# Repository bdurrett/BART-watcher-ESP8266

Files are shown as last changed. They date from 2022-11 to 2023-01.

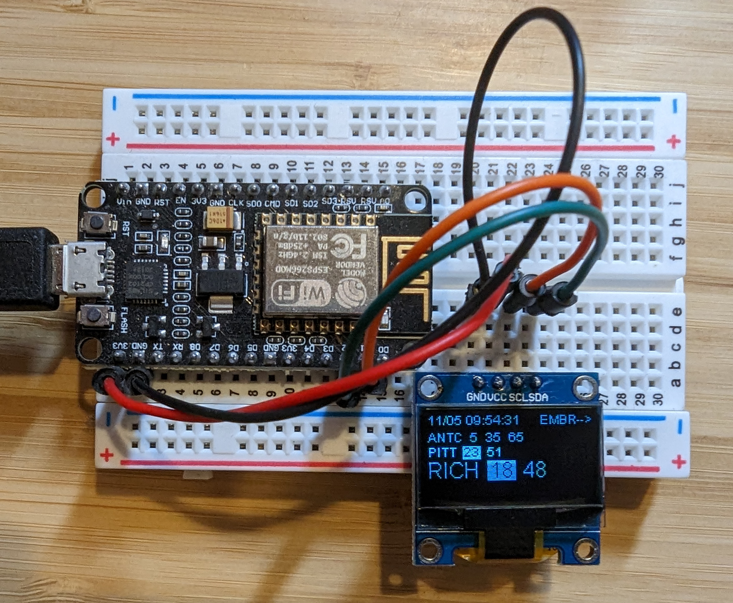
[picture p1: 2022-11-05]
assets/images/BART watcher full build.jpeg

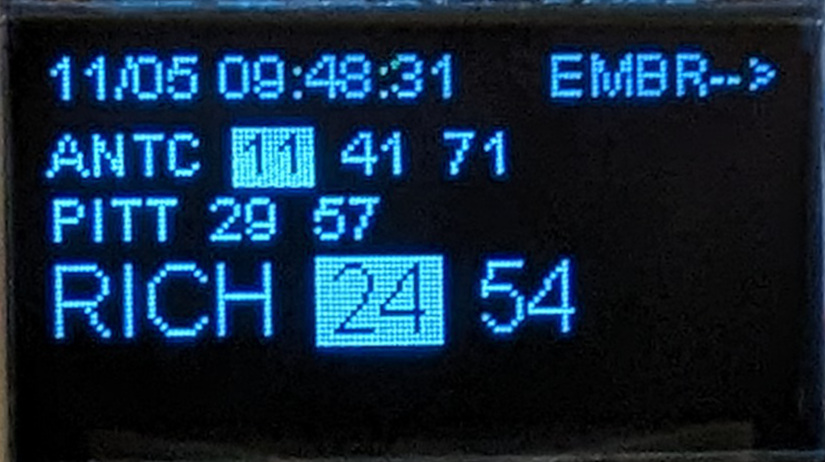
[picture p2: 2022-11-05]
assets/images/BART watcher screen closeup.jpeg

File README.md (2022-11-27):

# BART-watcher-ESP8266
Low power device to display relevant BART departures, ESP8266 and SSD1306 OLED display

## Overview
I frequently commute on BART and wanted a convenient way to tell when I should start walking to 
the train station, ideally something that is always accessible. Using a ESP8266 board and a ~1 inch
screen, I was able to see departing trains that meet my schedule.

The top line shows the date / time the station information was collected, and the departing 
station. The following lines are trains that are usable for the destination station, with the 
preferred (direct) lines in large type, and less-preferred (transfer needed) in small type. 
Finally, if a train is within the sweet spot where it isn't departing too soon to make it to 
the station but you also won't be waiting at the station too long, the departure time is 
highlighted, and the screen flashes briefly when updating to get attention.

* A number is minutes until departure
* "L" means the train is currently leaving
* "X" means the trains was cancelled (somewhat frequent these days)

In the example below, these are trains leaving Embarcadero for the North Berkeley station, Antioch and 
Berryessa Point lines require a transfer, Richmond line is direct. Two of the trains fit into the
departure sweet spot. 

Display close-up

### Interactive User Interface
If you add a button, a quick press will toggle the screen off and pause network updates. 
Another quick press will turn the screen back on and enable network updates. A long press (about 
3 seconds) will enter menu mode, where a quick press iterates through the menu items and a
long press exits menu mode. From the menu you can select the route (limited testing now) and
reset the wifi settings.

Menu

There is a little more contect on my blog, [BART Train Monitor with ESP8266 and SSD1306 display](https://brett.durrett.net/bart-train-monitor-with-esp8266-and-ssd1306-display/), and [3D Printed Case for ESP8266 and SSD1306 display](https://brett.durrett.net/3d-printed-case-for-esp8266-and-ssd1306-display/)

## Required Hardware
* ESP8266 board, any should work, [the ESP-12F is nice and tiny](https://smile.amazon.com/gp/product/B081PX9YFV/ref=ppx_yo_dt_b_asin_title_o01_s01?ie=UTF8&psc=1)
* SSD1306 OLED display, other types may work, I used [this one](https://smile.amazon.com/gp/product/B09C5K91H7/ref=ppx_yo_dt_b_asin_title_o01_s02?ie=UTF8&psc=1)

1. Connect ESP8266 D1, GPIO5 (SCL) to SCK on the SSD1306
2. Connect ESP8266 D2, GPIO4 (SDA) to SDA on the SSD1306
3. Connect ESP8266 GND and 3.3V to SSD1306 GND and VDD respectively

The completed build needs 4 wires and looks a little something like this (v1 screen layout shown):
BART watcher full build

### Optional Button
If you want to use the interactive hardware UI, install a momentary button!
* Some button (momentary switch)
* A 10 K ohm resistor (for pull down)

1. Connect ESP8266 D5, GPIO15 to one end of the switch
2. Connect one end ofthe 10 K ohm resistor to the same end of the switch, the other end of the resistor to GND
3. Connect the other end of the switch to 3.3V

With a button you get access to a menu! 

### Wiring Diagram

BART watcher wiring diagram

Wiring diagram created with [Fritzing](https://fritzing.org/)

### Sorta Fancy (okay, Janky) Case
I finally got around to tuning up my 3D printer and making a model. The case can be a bit tight... I thought I
was going to need to glue some things internally, but wiring pretty much compressed everything super snug. The 
button used is 6x6mm, the OLED matches the one linked, above.

Case

## Thank You
* [ThingPulse OLED SSD1306 (ESP8266/ESP32/Mbed-OS)](https://github.com/ThingPulse/esp8266-oled-ssd1306) rendering library
* [BART Legacy API](https://www.bart.gov/schedules/developers/api) for being early pioneers to the API game

## To Do
- [ ] Configuration requires a compile, this should be user configuable, likely via web page
- [X] Consider adding destination station to the display to reduce errors
- [X] 3D Print some form of a case to make it tidy on a desk

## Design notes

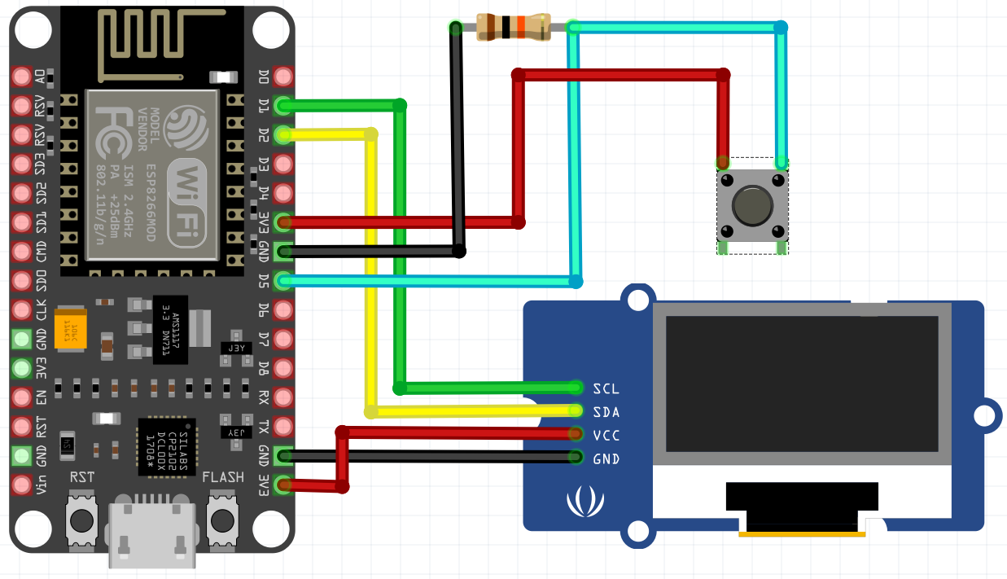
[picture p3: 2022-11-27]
assets/images/BART watcher breadboard.png

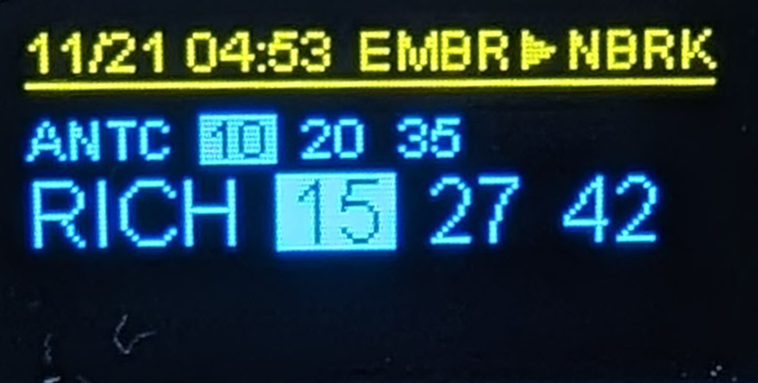
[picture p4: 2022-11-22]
assets/images/Two color schedule.jpg

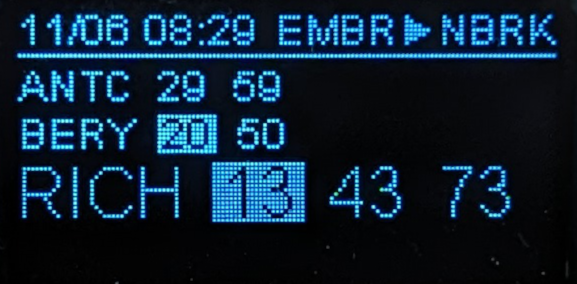
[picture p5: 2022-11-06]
assets/images/BART watcher display layout v2.png

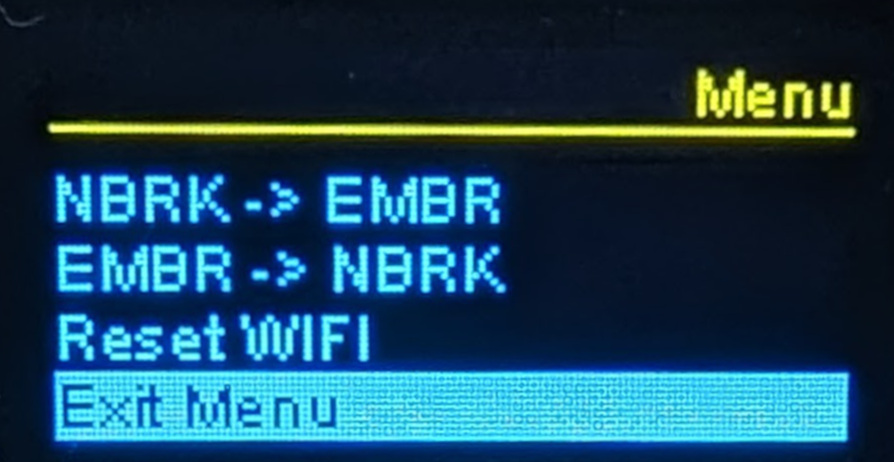
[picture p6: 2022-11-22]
assets/images/two color menu.jpg

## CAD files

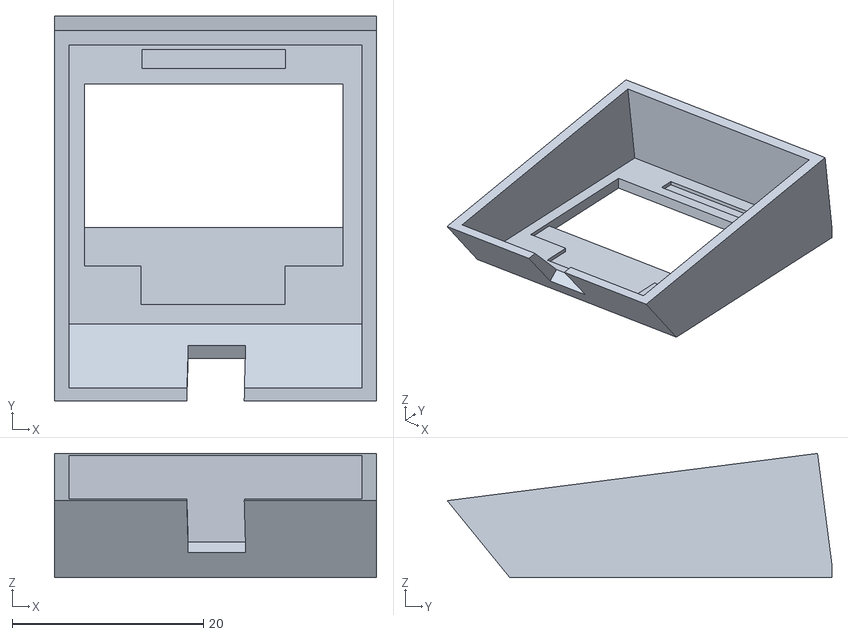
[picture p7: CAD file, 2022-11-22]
assets/3D files/Cover with OLED and button.stl
33.6 x 40.2 x 13.0

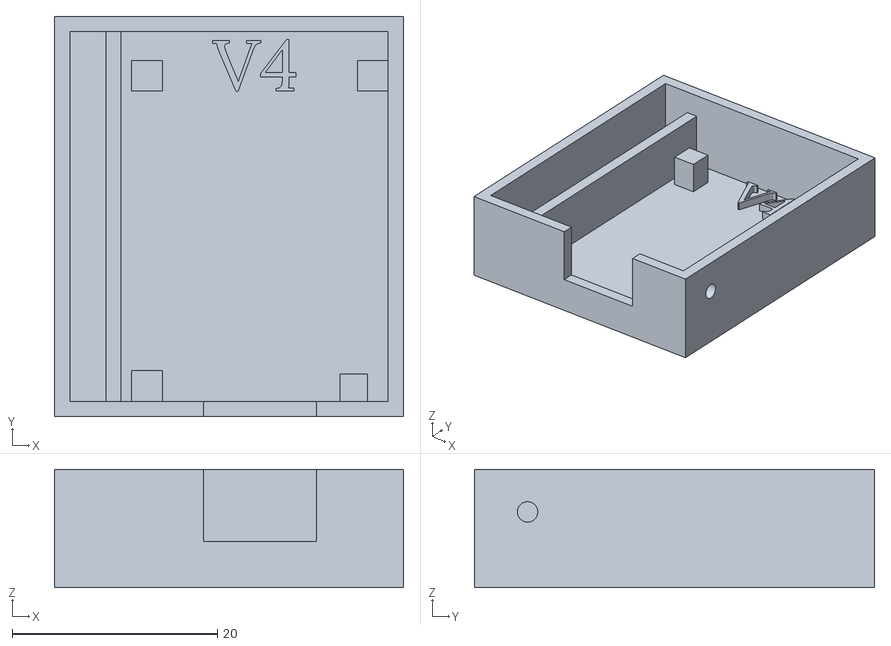
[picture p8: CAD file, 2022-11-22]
assets/3D files/ESP-12F base.stl
34.0 x 39.0 x 11.5

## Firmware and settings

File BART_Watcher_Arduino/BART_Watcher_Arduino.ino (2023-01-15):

#include <WiFiManager.h>              // https://github.com/tzapu/WiFiManager WiFi Configuration Magic (v. 2.0.3-alpha)
#include <ArduinoJson.h>              // https://github.com/bblanchon/ArduinoJson (v. 6.7.13)
#include <ArduinoOTA.h>               // https://github.com/jandrassy/ArduinoOTA (v. 1.0.5)
#include <SPI.h>
#include <Wire.h>
#include <ESP8266WiFi.h>
#include <ESP8266HTTPClient.h>
#include <Arduino.h>
#include <WiFiClient.h>
#include "SSD1306Wire.h"              // https://github.com/ThingPulse/esp8266-oled-ssd1306

const char compile_date[] = __DATE__ " " __TIME__;

// Set to true if hardware button connected (with pullup), false otherwise 
const bool buildHasButton = true;

const int buttonPin = 14;             // GPIO14, D5 on board

const int screenSaverMinutes = 60;    // automatically turn on screen saver

// Currently using the shared legacy API key, https://www.bart.gov/schedules/developers/api
// this may be revoked at any time, get your own personal key
String bartApiKey = "MW9S-E7SL-26DU-VV8V";

// Line height for each font size
int smallLineHeight = 11;
int bigLineHeight = 16;

// Global wifi manager instance
WiFiManager wifiManager;

// Global display instance 
SSD1306Wire display(0x3c, SDA, SCL);  // ADDRESS, SDA, SCL

String startingStation = "EMBR";
String endingStation = "NBRK";
String directionNeeded = "North";
bool redLineOption = true;
bool redLinePreferred = true;
bool orangeLineOption = true;
bool orangeLinePreferred = true;
bool yellowLineOption = true;
bool yellowLinePreferred = false;
bool blueLineOption = false;
bool blueLinePreferred = false;
bool greenLineOption = false;
bool greenLinePreferred = false;
int notEnoughMinutes = 9;
int tooManyMinutes = 16;


void setup() {
  Serial.begin(115200);         // Start the Serial communication to send messages to the computer
  delay(50);
  Serial.println('\n');
  Serial.print( "Built: " );
  Serial.println(compile_date);
  Serial.println("entering setup()");

  // Init display
  Serial.println("Initializing SSD1306");  
  display.init();
  display.normalDisplay();
  display.flipScreenVertically();
  display.displayOn();

  // Title Screen
  display.clear();  
  display.setColor( WHITE );        
  display.setFont(ArialMT_Plain_16);
  display.setTextAlignment( TEXT_ALIGN_CENTER );
  display.drawString( 64, 0, "BART Watcher" );
  display.display();

  Serial.println("starting Wifi manager");
  wifiManager.setAPCallback(configModeCallback);
  String mac = WiFi.macAddress();
  mac.replace( ":", "" );
  Serial.print("Got MAC address: " );
  Serial.println(WiFi.macAddress());
  Serial.print("Got IP address: " );
  Serial.println(WiFi.localIP());         // Send the IP address of the ESP8266 to the computer
  wifiManager.autoConnect();

  // Uncomment to pull new station list for paste into code (usually one-off)
  // parseStationNames();


  // Load initial schedule
  refreshStationData();

  if( buildHasButton ){
    Serial.println("Software configured to use hardware button (if not attached, random behavior expected)");
    pinMode(buttonPin, INPUT);

    if( buttonPushed() ){
      Serial.println("Button is pushed");
    }
    else{
      Serial.println("Button is not pushed");
    }
  }
  else{
    Serial.println("Software configured to not use hardware button, menu and sleep functionality not accessible");
  }
}

void configModeCallback (WiFiManager *myWiFiManager) {
  Serial.println("Wifi entered config mode");
  Serial.println(WiFi.softAPIP());
  Serial.println(myWiFiManager->getConfigPortalSSID());
  display.setColor( WHITE );        
  display.setFont(ArialMT_Plain_10);
  display.setTextAlignment( TEXT_ALIGN_CENTER );
  display.drawString( 64, 18, "Setup via wifi" );
  display.drawString( 64, 28, "AP: " + myWiFiManager->getConfigPortalSSID() );
  display.drawString( 64, 38, "IP: " + WiFi.softAPIP().toString() );
  display.display();

}

unsigned long lastButtonDown = 0;
unsigned long lastScheduleUpdate = 0;
unsigned long screenOnSince = 0;

void loop() {
  static bool isActive = true;
  static bool inMenu = false;

  if( isActive == true ){
    if( screenOnSince == 0 ){
      // first run or reset
      screenOnSince = millis();
    }
    else{
      // see if screen saver triggered
      if( ( millis() - screenOnSince ) / 60000 >= screenSaverMinutes ) {
        Serial.println("Automatically entering screen saver mode");  
        display.displayOff();
        isActive = false;
        inMenu = false;
        screenOnSince = 0;
      }
    }
  }

  if( inMenu == true ){
    if( inMenu = menuLoop() ){
      // still in menu mode
    }
    else{
      // exiting menu mode, force refresh of schedule
      display.clear();  
      display.display();        
      lastScheduleUpdate = 0;
      blinkScreen( 7, 50 );
    }
    return;
  }

  // Check for button press
  if( buttonPushed() ){
    if( lastButtonDown != 0 ){
      // button is pressed, long enough to enter menu mode?
      if( millis() - lastButtonDown > 3000 ){
        Serial.println("Entering menu mode");
        lastButtonDown = 0;
        display.displayOn();
        isActive = true;     
        inMenu = true;
        blinkScreen( 7, 50 );
      }
    }
    else{
      lastButtonDown = millis();
    }
  }  
  else{
    // short press?
    if( ( lastButtonDown != 0 ) && ( millis() - lastButtonDown > 50 ) ){
      // switch between active / inactive
      if( isActive ){
        display.displayOff();
        isActive = false;
      }
      else{
        display.displayOn();
        isActive = true;      }
    }
    lastButtonDown = 0;
  }

  
  if( isActive ){
    // Check if time to update schedule
    if( millis() - lastScheduleUpdate > 30 * 1000 ){
      if( refreshStationData() > 0 ){
        blinkScreen( 3, 150 );
      }
      lastScheduleUpdate = millis();
    }
  }
}

bool menuLoop() {
  static int menuItem = 0;
  static int drawnMenuItem = -1;

  if( drawnMenuItem != menuItem ){
    renderMenu( menuItem );
    drawnMenuItem = menuItem; 
  }

  // Check for button press
  if( buttonPushed() ){
    if( lastButtonDown != 0 ){
      // check for long press
      if( millis() - lastButtonDown > 3000 ){
        // Select menu item
        switch( menuItem ){
          case 0:
            setStations( "NBRK", "EMBR" );
            break;
          case 1:
            setStations( "EMBR", "NBRK" );
            break;
          case 2: 
            Serial.println("Erasing wifi config, restarting");
            wifiManager.resetSettings();
            ESP.restart();
            break;
          case 3:
            Serial.println("Exiting menu mode");
            break;
        }
        lastButtonDown = 0;
        drawnMenuItem = -1;
        return( false );
      }
    }
    else{
      lastButtonDown = millis();
    }
  }
  else{
    if( ( lastButtonDown != 0 ) && ( millis() - lastButtonDown > 50 ) ){
      // short press
      if( ++menuItem > 3 ) menuItem = 0;
    }
    lastButtonDown = 0;
  }
  
  return( true );
}

/*
 *  Get button state
 *  returns: true if pressed, false if not pressed or no hardware button connected
 */
bool buttonPushed(){
  if( buildHasButton == false ){
    return( false );
  }
  
  if( digitalRead(buttonPin) == HIGH ){
    return( true );
  }
  return( false );
}

/*
 *  Draw the menu
 *  highlight = menu item to highlight, 0 = first item
 */
void renderMenu( int highlight ){
  highlight++;
  
  display.clear();  
  display.setColor( WHITE );        
  display.setFont(ArialMT_Plain_10);
  int yPos = 0; 

  display.setTextAlignment( TEXT_ALIGN_RIGHT );
  display.drawString( 128, yPos, "Menu" );
  
  // On dual-color displays, this moves schedule to second color of screen   
  yPos += smallLineHeight + 4;
  
  // Line looks fancy
  display.drawLine( 0, 12, 128, 12 );
  
  display.setTextAlignment( TEXT_ALIGN_LEFT );
  display.drawString( 0, yPos, "NBRK -> EMBR" );
  yPos += smallLineHeight;
  display.drawString( 0, yPos, "EMBR -> NBRK" );
  yPos += smallLineHeight;
  display.drawString( 0, yPos, "Reset WIFI" );
   yPos += smallLineHeight;
  display.drawString( 0, yPos, "Exit Menu" );
 
  display.setColor( INVERSE );
  display.fillRect(0, ( highlight*smallLineHeight ) + 5, 128, smallLineHeight);
  display.display();
}

/*
 *  Switch between inverted and normal screen, ideally to draw attention
 *  blinks: the nymber of normal / invert cycles
 *  msecBetween: millis between each tansition (2 per cycle)
 */
void blinkScreen( int blinks, int msecBetween ) {

  for( int i = 0; i < blinks; i++ ){
    display.invertDisplay();
    delay( msecBetween );
    display.normalDisplay();
    delay( msecBetween );
  }
}

/*
 *  Pull updated data from BART, render relevant departure infomration to screen 
 *  returns non-zero if there is a departure on a preferred line in the ideal 
 *  departure time 
 */
int refreshStationData() {
  String url = String( "https://api.bart.gov/api/etd.aspx?cmd=etd&orig=" + startingStation + "&key="  + bartApiKey + "&json=y" );
  String bartresponse = httpsGETRequest( url.c_str() );

  // Serial.println(bartresponse);
  
  DynamicJsonDocument doc(20000);
  deserializeJson(doc, bartresponse);

  if ( doc.isNull() ) {
    Serial.println("Parsing JSON real time departures failed!");
    return( 0 );
  }

  int preferredTrains = 0;
  int yPos = 0;

  display.clear();  
  display.setColor( WHITE );        
  display.setFont(ArialMT_Plain_10);

  // Show start and end stations
  display.setTextAlignment( TEXT_ALIGN_RIGHT );
  display.drawString( 128, 0, endingStation );
  // annoying I can't find a character for an arrow
  int xOff = display.getStringWidth( endingStation );
  xOff += 3;
  display.fillTriangle( 128-xOff, 6, 128-xOff-5, 3, 128-xOff-5, 9 );  
  display.drawString( 128-xOff-7, 0, String( startingStation ) );
  
  // Show date & time of data pull
  display.setTextAlignment( TEXT_ALIGN_LEFT );
  String datetime = String( doc["root"]["date"] ).substring(0,5) + " " + String( doc["root"]["time"] ).substring(0,5);
  Serial.println(datetime);
  display.drawString( 0, 0, datetime );

  // Line looks fancy
  display.drawLine( 0, 12, 128, 12 );

  // On dual-color displays, this moves schedule to second color of screen   
  yPos += smallLineHeight + 3;

  display.setTextAlignment( TEXT_ALIGN_LEFT );

  for( int i=0; i < doc["root"]["station"][ 0 ]["etd"].size(); i++ ){

    JsonObject dest = doc["root"]["station"][ 0 ]["etd"][ i ];

    // Is the destination relevant and preferred?
    bool skip = false;
    bool preferred = false;

    // Okay to look at just first item as all trains w/ destination share direction / line
    JsonObject sample = dest["estimate"][ 0 ];

    // Only show trains going in the correct direction
    if( ! String( sample[ "direction" ] ).equalsIgnoreCase( directionNeeded ) ){
      skip = true; 
    }

    // See if this line is an option, and if so, is it the preferred line?
    if( String( sample[ "color" ] ).equalsIgnoreCase( "RED" ) ){
      if( ! redLineOption ) skip = true;
      if( redLinePreferred ) preferred = true;
    }
    else if( String( sample[ "color" ] ).equalsIgnoreCase( "ORANGE" ) ){
      if( ! orangeLineOption ) skip = true;
      if( orangeLinePreferred ) preferred = true;
    }
    else if( String( sample[ "color" ] ).equalsIgnoreCase( "YELLOW" ) ){
      if( ! yellowLineOption ) skip = true;
      if( yellowLinePreferred ) preferred = true;
    }
    else if( String( sample[ "color" ] ).equalsIgnoreCase( "BLUE" ) ){
      if( ! blueLineOption ) skip = true;
      if( blueLinePreferred ) preferred = true;
    }
    else if( String( sample[ "color" ] ).equalsIgnoreCase( "GREEN" ) ){
      if( ! greenLineOption ) skip = true;
      if( greenLinePreferred ) preferred = true;
    }

    if( ! skip ){
      if( preferred ){
        preferredTrains += updateDestination( dest, 0, yPos, true );
        yPos += bigLineHeight;
      }
      else{
        updateDestination( dest, 0, yPos, false );
        yPos += smallLineHeight;
      }
    }
  }
  display.display();      // Show updated information on screen
  
  return( preferredTrains );
}

/*
 *  Display a single line of a destination, stations name and minutes to departure
 *  returns: the numoer of trains that are in the ideal departure timeframe
 */
int updateDestination( JsonObject dest, int x, int y, bool large ){
  if( large ){
    display.setFont(ArialMT_Plain_16);
  }
  else{
    display.setFont(ArialMT_Plain_10);
  }
  
  display.drawString( x, y, String( dest["abbreviation"] ) );
  x += display.getStringWidth( String( dest["abbreviation"] ) + "  " );

  int idealSchedule = 0;

  JsonArray estimates = dest["estimate"];
  for( int j=0; j < estimates.size(); j++ ){
    
    String output;
    
    if( int( estimates[j]["cancelflag"] ) != 0 ){
      output = "X";
    }
    else if( String( estimates[j]["minutes"]).equalsIgnoreCase( "Leaving" ) ){
      output = "L";
    }
    else{
      int mins = int( estimates[j]["minutes"] );
      output = String( mins );
      // See if this is an ideal / sweet spot train, not too soon to catch, not too long to wait
      if( mins >= notEnoughMinutes && mins <= tooManyMinutes ){
        idealSchedule++;
        int width = display.getStringWidth( output );
        if( large ){
          display.fillRect( x-2, y+2, width+4, 17-3);
        }
        else{
          display.fillRect( x-1, y+2, width+2, 12-3);
        }
        display.setColor( BLACK );        // Draw white text
      }
    }
    display.drawString( x, y, output );
    display.setColor( WHITE );        // Draw white text

    x += display.getStringWidth( output + "  " );
    
  }  
  return( idealSchedule );
}

/*
 *  Super kluge - update parameters based on souce and destination station codes
 *  very hacky for now
 *  returns true if combination supported, false otherwise
 */
bool setStations( String starting, String ending ){

  if( ( starting == "NBRK" ) && ( ending == "EMBR" ) ){
    startingStation = "NBRK";
    endingStation = "EMBR";
    directionNeeded = "South";
    redLineOption = true;
    redLinePreferred = true;
    orangeLineOption = true;
    orangeLinePreferred = false;
    yellowLineOption = false;
    yellowLinePreferred = false;
    blueLineOption = false;
    blueLinePreferred = false;
    greenLineOption = false;
    greenLinePreferred = false;
    notEnoughMinutes = 7;
    tooManyMinutes = 14;
    return( true );
  }

  if( ( starting == "EMBR" ) && ( ending == "NBRK" ) ){
    startingStation = "EMBR";
    endingStation = "NBRK";
    directionNeeded = "North";
    redLineOption = true;
    redLinePreferred = true;
    orangeLineOption = true;
    orangeLinePreferred = true;
    yellowLineOption = true;
    yellowLinePreferred = false;
    blueLineOption = false;
    blueLinePreferred = false;
    greenLineOption = false;
    greenLinePreferred = false;
    notEnoughMinutes = 9;
    tooManyMinutes = 16;
    return( true );
  }

  return( false );
}


/*
 *  Unused for now, clumsy way to get station code from name
 */
String stationAbbreviation( String name ){
  if( name.equalsIgnoreCase( "12th St. Oakland City Center" ) ) return "12TH";
  if( name.equalsIgnoreCase( "16th St. Mission" ) ) return "16TH";
  if( name.equalsIgnoreCase( "19th St. Oakland" ) ) return "19TH";
  if( name.equalsIgnoreCase( "24th St. Mission" ) ) return "24TH";
  if( name.equalsIgnoreCase( "Antioch" ) ) return "ANTC";
  if( name.equalsIgnoreCase( "Ashby" ) ) return "ASHB";
  if( name.equalsIgnoreCase( "Balboa Park" ) ) return "BALB";
  if( name.equalsIgnoreCase( "Bay Fair" ) ) return "BAYF";
  if( name.equalsIgnoreCase( "Berryessa/North San Jose" ) ) return "BERY";
  if( name.equalsIgnoreCase( "Castro Valley" ) ) return "CAST";
  if( name.equalsIgnoreCase( "Civic Center/UN Plaza" ) ) return "CIVC";
  if( name.equalsIgnoreCase( "Coliseum" ) ) return "COLS";
  if( name.equalsIgnoreCase( "Colma" ) ) return "COLM";
  if( name.equalsIgnoreCase( "Concord" ) ) return "CONC";
  if( name.equalsIgnoreCase( "Daly City" ) ) return "DALY";
  if( name.equalsIgnoreCase( "Downtown Berkeley" ) ) return "DBRK";
  if( name.equalsIgnoreCase( "Dublin/Pleasanton" ) ) return "DUBL";
  if( name.equalsIgnoreCase( "El Cerrito del Norte" ) ) return "DELN";
  if( name.equalsIgnoreCase( "El Cerrito Plaza" ) ) return "PLZA";
  if( name.equalsIgnoreCase( "Embarcadero" ) ) return "EMBR";
  if( name.equalsIgnoreCase( "Fremont" ) ) return "FRMT";
  if( name.equalsIgnoreCase( "Fruitvale" ) ) return "FTVL";
  if( name.equalsIgnoreCase( "Glen Park" ) ) return "GLEN";
  if( name.equalsIgnoreCase( "Hayward" ) ) return "HAYW";
  if( name.equalsIgnoreCase( "Lafayette" ) ) return "LAFY";
  if( name.equalsIgnoreCase( "Lake Merritt" ) ) return "LAKE";
  if( name.equalsIgnoreCase( "MacArthur" ) ) return "MCAR";
  if( name.equalsIgnoreCase( "Millbrae" ) ) return "MLBR";
  if( name.equalsIgnoreCase( "Milpitas" ) ) return "MLPT";
  if( name.equalsIgnoreCase( "Montgomery St." ) ) return "MONT";
  if( name.equalsIgnoreCase( "North Berkeley" ) ) return "NBRK";
  if( name.equalsIgnoreCase( "North Concord/Martinez" ) ) return "NCON";
  if( name.equalsIgnoreCase( "Oakland International Airport" ) ) return "OAKL";
  if( name.equalsIgnoreCase( "Orinda" ) ) return "ORIN";
  if( name.equalsIgnoreCase( "Pittsburg/Bay Point" ) ) return "PITT";
  if( name.equalsIgnoreCase( "Pittsburg Center" ) ) return "PCTR";
  if( name.equalsIgnoreCase( "Pleasant Hill/Contra Costa Centre" ) ) return "PHIL";
  if( name.equalsIgnoreCase( "Powell St." ) ) return "POWL";
  if( name.equalsIgnoreCase( "Richmond" ) ) return "RICH";
  if( name.equalsIgnoreCase( "Rockridge" ) ) return "ROCK";
  if( name.equalsIgnoreCase( "San Bruno" ) ) return "SBRN";
  if( name.equalsIgnoreCase( "San Francisco International Airport" ) ) return "SFIA";
  if( name.equalsIgnoreCase( "San Leandro" ) ) return "SANL";
  if( name.equalsIgnoreCase( "South Hayward" ) ) return "SHAY";
  if( name.equalsIgnoreCase( "South San Francisco" ) ) return "SSAN";
  if( name.equalsIgnoreCase( "Union City" ) ) return "UCTY";
  if( name.equalsIgnoreCase( "Walnut Creek" ) ) return "WCRK";
  if( name.equalsIgnoreCase( "Warm Springs/South Fremont" ) ) return "WARM";
  if( name.equalsIgnoreCase( "West Dublin/Pleasanton" ) ) return "WDUB";
  if( name.equalsIgnoreCase( "West Oakland" ) ) return "WOAK";
  
  return( "UNKN" );
}

/*
 * Helper routine to pull names but easier to just store locally
 */
void parseStationNames(){
  String url = String( "https://api.bart.gov/api/stn.aspx?cmd=stns&key=" + bartApiKey + "&json=y" );
  String bartresponse = httpsGETRequest( url.c_str() );

  DynamicJsonDocument doc(20000);
  deserializeJson(doc, bartresponse);

  if ( doc.isNull() ) {
    Serial.println("Parsing JSON list of BART stations failed!");
    return;
  }
  
  int numStations = doc["root"]["stations"]["station"].size();

  for( int i=0; i < numStations; i++ ){

    Serial.print( "if( name.equalsIgnoreCase( \"" );
    Serial.print( String( doc["root"]["stations"]["station"][ i ]["name"] ) );
    Serial.print( "\" ) ) return \"" );
    Serial.print( String( doc["root"]["stations"]["station"][ i ]["abbr"] ) );
    Serial.println( "\";" );
  }
}

String httpsGETRequest(const char* serverName) {
  std::unique_ptr<BearSSL::WiFiClientSecure>client(new BearSSL::WiFiClientSecure);

  // client->setFingerprint(fingerprint);
  // Or, if you happy to ignore the SSL certificate, then use the following line instead:
  client->setInsecure();

  HTTPClient https;
  String payload = "{}"; 

  Serial.print("[HTTPS] begin...\n");
  if (https.begin(*client, serverName)) {  // HTTPS

    Serial.print("[HTTPS] GET...\n");
    // start connection and send HTTP header
    int httpCode = https.GET();

    // httpCode will be negative on error
    if (httpCode > 0) {
      // HTTP header has been send and Server response header has been handled
      Serial.printf("[HTTPS] GET... code: %d\n", httpCode);

      // file found at server
      if (httpCode == HTTP_CODE_OK || httpCode == HTTP_CODE_MOVED_PERMANENTLY) {
        payload = https.getString();
        Serial.println(payload);
      }
    } else {
      Serial.printf("[HTTPS] GET... failed, error: %s\n", https.errorToString(httpCode).c_str());
    }

    https.end();
  } else {
    Serial.printf("[HTTPS] Unable to connect\n");
  }
  return( payload );
}

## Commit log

2022-11-06 Add nicer display formatting, update station list, increase JSON buffer sizes, include wiring diagram
2022-11-08 Add hardware button functionality, inactive mode (basically sleep, no screen or network), interactive menus
2022-11-12 Add option to disable button, update default times for "sweet spot" departures
2022-11-22 Adding 3D files (stl) for a case, photos of the case and multi-color display
    [Cover with OLED and button.stl, ESP-12F base.stl]
2022-11-27 Add wiring diagram
2022-12-12 Add automatic screen saver timer
